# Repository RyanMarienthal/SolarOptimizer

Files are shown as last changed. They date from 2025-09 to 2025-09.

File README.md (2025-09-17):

This project contains the design of a solar power optimizer.

The project was designed in KiCad, and the files are provided and can be edited to the users demands.

The project has generic values for R1, R2, R3, and R4 because they are intended to be chosen by the user depending on the voltage of the system.

Standard divider sizes are shown below:
  48V OCV: R1 = 40kOhm, R2 = 7500Ohm, R3 = 1000Ohm, R4 = 2000Ohm
  R1 and R2 must be rated for at least 1/8 Watt.
  R3 and R4 must be rated for at least 1 Watt.

  24V OCV: R1 = 16kOhm, R2 = 2000Ohm, R3 = Short, R4 = Open
  R1 and R2 must be rated for at least 1/8 Watt

  20V OCV: R1 = 12500, R2 = 7500, R3 = Short, R4 = Open

Production files are aslo included, the zip file and BOM are formatted for JLCPCB manufacturing and assembly.

If another software is used, these may need to be altered.

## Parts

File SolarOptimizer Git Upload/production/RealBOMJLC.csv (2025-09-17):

Comment | Designator | Footprint | JLCPCB Part #（optional）
CL21B104KBCNNNC | C1 | 0805 | C1711
HHV0805R7105K101NSLJ | C2 | 0805 | C22367837
DG636-7.62-02P-14-00A(H) | J2 | 插件,P=7.62mm | C581337
SI2306 | Q1_N | SOT-23 | C727154
AO3407 | Q2_P | SOT-23 | C727158
0805W8F3300T5E | R7 | 0805 | C17630
0805W8F1002T5E | R10 | 0805 | C17414
0805W8F4701T5E | R3_4K7 | 0805 | C17673
0805W8F4700T5E | R5_470 | 0805 | C17710
0805W8F1004T5E | R61M | 0805 | C17514
3362P-1-203LF | RP1 | 插件-3P,7x6.6mm | C81263
3362P-1-104LF | RP3 | 插件-3P,7x6.6mm | C81266
TLV1805DBVR | U1 | SOT-23-6 | C702104
LM317LCDR | U2 | SOIC-8 | C105219

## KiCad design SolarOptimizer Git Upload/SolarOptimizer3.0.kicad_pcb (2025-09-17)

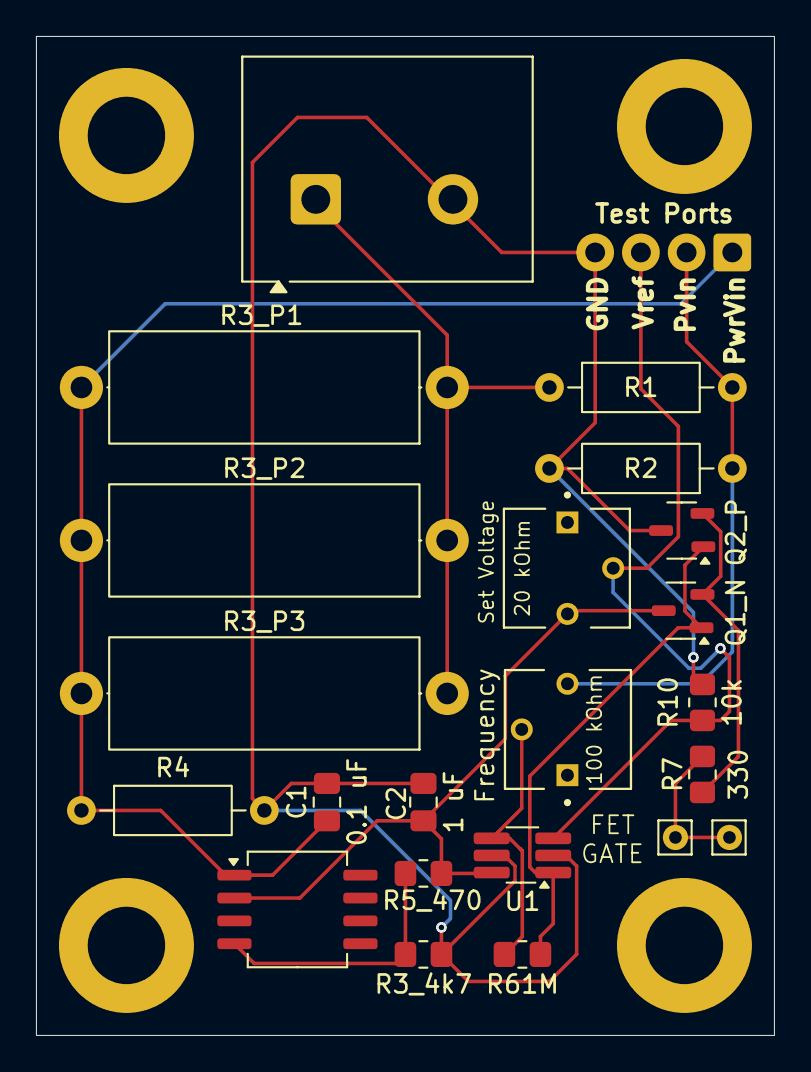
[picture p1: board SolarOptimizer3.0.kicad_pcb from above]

Board: 2 copper layers, 41.0 x 55.5 mm, 27 parts (0 on the bottom side), 11 nets.

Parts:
C1: 0.1 uF; C_0805_2012Metric_Pad1.18x1.45mm_HandSolder
C2: 1 uF; C_0805_2012Metric_Pad1.18x1.45mm_HandSolder
H3, H4, H5, H6: MountingHole; MountingHole_4.3mm_M4_DIN965_Pad
J1, J3: Pin_D0.7mm_L6.5mm_W1.8mm_FlatFork
J2: Screw_Terminal_01x02; TerminalBlock_gauge 10
J5: Screw_Terminal_01x04; 4Pin_Terminal_NoSilk
Q1_N: N-Channel; SOT-23-3
Q2_P: P-Channel; SOT-23-3
R1, R2, R4: R; R_Axial_DIN0207_L6.3mm_D2.5mm_P10.16mm_Horizontal
R3_4k7: 4k7; R_0805_2012Metric_Pad1.20x1.40mm_HandSolder
R3_P1, R3_P2, R3_P3: R; R_Axial_DIN0617_L17.0mm_D6.0mm_P20.32mm_Horizontal
R5_470: 470; R_0805_2012Metric_Pad1.20x1.40mm_HandSolder
R7: 330; R_0805_2012Metric_Pad1.20x1.40mm_HandSolder
R10: 10k; R_0805_2012Metric_Pad1.20x1.40mm_HandSolder
R61M: 1 MOhm; R_0805_2012Metric_Pad1.20x1.40mm_HandSolder
Rp1: 20 kOhm; TRIM_3362P-1-253LF
Rp3: 100 kOhm; TRIM_3362P-1-253LF
U1: TLV1805DBVR; TSOT-23-6_HandSoldering
U2: LM317LCDR; SOIC-8_5.3x6.2mm_P1.27mm

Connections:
+CompIn: R61M.2, Rp3.2, U1.4 (IN+)
/HVDC Line: J2.1, R1.1, R3_P1.1, R3_P2.1, R3_P3.1
CompOut: Q1_N.1 (G), Q2_P.1 (G), R61M.1, U1.1 (OUT)
GND: C1.2, C2.2, J2.2, J5.4, Q2_P.2 (D), R2.2, R3_4k7.1, R4.2, R10.2, U1.2 (V-), U1.5 (SD)
unnamed: J1.1, J3.1, R7.2
unnamed: Q1_N.3 (S), Q2_P.3 (S), R7.1
unnamed: R3_4k7.2, R5_470.2, U2.4 (ADJUSTMENT)
PV Input: J5.2, R1.2, R2.1, Rp3.3
RefIn: J5.3, R10.1, Rp1.2, U1.3 (IN-)
RegIn: C1.1, J5.1, R3_P1.2, R3_P2.2, R3_P3.2, R4.1, U2.1 (IN)
RegOut: C2.1, Q1_N.2 (D), R5_470.1, Rp1.3, U1.6 (V+), U2.2 (OUT)
